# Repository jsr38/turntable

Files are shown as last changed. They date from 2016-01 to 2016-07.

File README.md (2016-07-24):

# turntable
3D scanning turntable

This repository contains hardware designs and firmware to enable a 3D scanning turntable to be constructed.

The turntable operates with either a mains AC motor with feedback or a DC motor.  In both cases a rotary optical encoder is employed to give accurate feedback of current position to upper software layers.

In my fork of the [bqlabs/horus](https://github.com/jsr38/horus) repository you can find my modifications to the bqlabs/horus scanning software which allow either a pair of laser line emitters and RGB camera or a Microsoft Kinect V2 aka Kinect One which contains an IR depth sensor and RGB camera, allowing full colour but lower resolution scans under Linux or Mac OS X.

The turntable electronics are designed to interface to an Arduino Uno as a pair of expansion shields.

opto-interface:
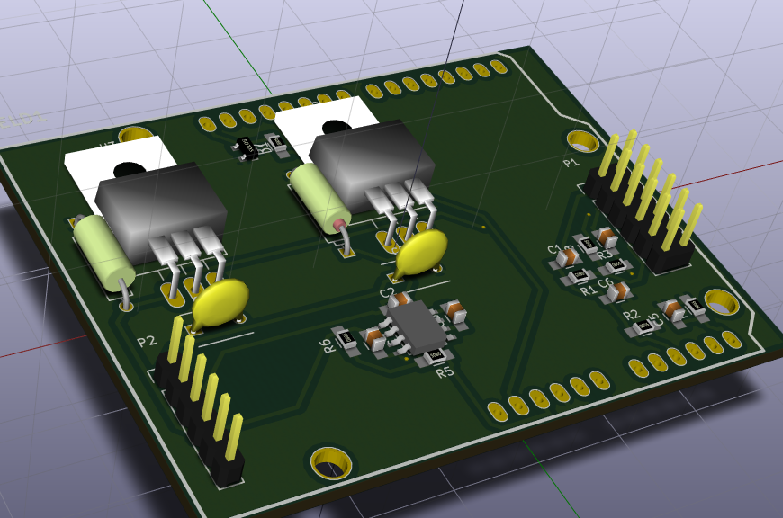
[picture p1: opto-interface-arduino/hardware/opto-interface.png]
Opto Encoder Interface


opto-interface prototype:
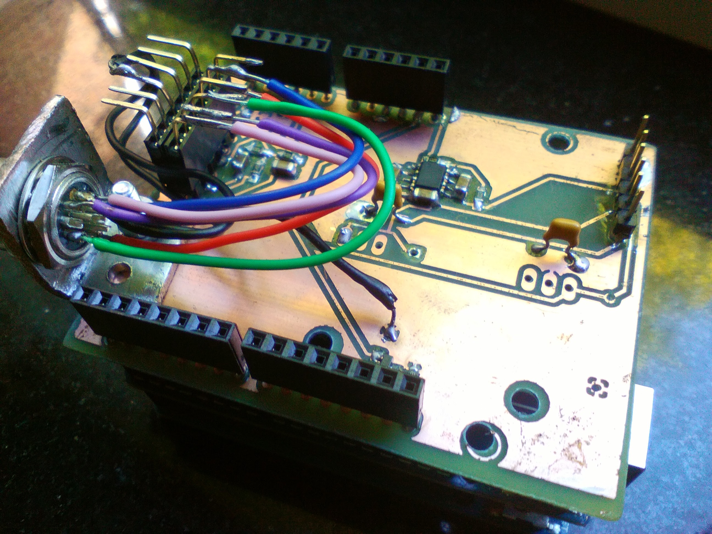
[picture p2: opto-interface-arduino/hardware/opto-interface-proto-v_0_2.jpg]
Opto Encoder Interface Prototype v0.2


* [first movements](https://youtu.be/DPcl0FW12F8)

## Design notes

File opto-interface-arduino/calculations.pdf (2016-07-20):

## 1 MAX889 Charge pump IC

———————
We have MAX889S variant.
PART FREQUENCY C FLY C OUT C IN REGULATED C IN FREE-RUN MAX889S 1MHz 2.2F 10F 10F 2.2F
Output Ripple mV vs Load Current substituting C OUT and a load I=50-100mA , ripple ought to be 5-8mV. Is this OK?
We don’t know because we don’t know exactly what’s inside and there is no indication on the encoder’s datasheet as to tolerance of supply noise/ripple. Ripple should be fundamentally located @fOSC which is 1MHz, so filtering should be straightforward given our estimate for encoder signals of DO SUMS
From the datasheet,

R1 ≤

Vref
30µA

R2 <

−Vout
30µA

Calculate for 12V input and reference at 5V.

R1 ≤

5
30µA = 167kR

R2 <

5
30µA = 167kR

Choose R1 to be less than or equal 100kR.

R1 = 100kR

R2 = R1

Vout

−Vref
=

100e3 − 5
−5

= 100kR

Calculate for 12V input and reference at 12V.

R1 ≤

12
30µA = 400kR

R2 <

5
30µA = 167kR

1

2 Design input filter using spice.

——————————–
Operating fundamental frequency for encoder: 81, 000 ∗ 2 ∗ π rad rev⁻¹ @ 1 rev s⁻¹ maximum, ≥ 81kHz so cutoff ought to be > 100kHz.
Output O/C impedance is 110 ohms @ 100kHz.
Voltage divider to find 600mV between 0V and 5V:

Vout = Vin

Z1
Z1 + Z2

⇒

0.6
5

− 1

Z1 +

0.6
5

Z2 = 0 ⇒ Z1 =

5
0.6

− 1

Z2

If Z2 = 100kR then Z1 = 733kR

### 2.1 Schematic model

### 2.2 Model response

3 Arduino sample rates.

———————
15k SPS or 76.9k SPS at lowest resolution.

2

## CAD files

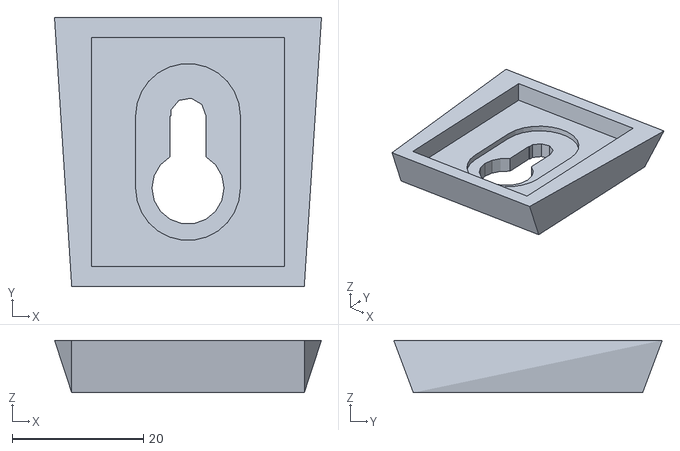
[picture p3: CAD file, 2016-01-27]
tripod/501PL.stl
40.8 x 41.0 x 8.00

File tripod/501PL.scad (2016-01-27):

// A replacement plate for Manfrotto 501PL quick release compatible heads
// by Nirav Patel <http://eclecti.cc>
//
// Altered to suit Velbon Sherpa 250 with PH-157Q
// JSR 2016 

// Available under the CC BY license

channel = 5.5;              // Width of the channel in the middle
height = 8.0;               // Height of the plate (>=11 mm recommended)
length = 19.0 * 2.0 + 3.0; // Length of the plate (90 mm is the stock one)
wall = 3;                   // Thickness of walls
width = 35.5;              // Width of the main cube structure
channel_offset = width / 2.0;

tan_theta = 2.625 / length;

module tapered() polyhedron(points = [[-2.625,0,0], [0,wall,height], [0,0,0], [0,length,0], [0,length - wall,height], [0,length,0]],
        faces = [[0,1,2], [0,4,1], [0,3,4], [0,5,3], [0,2,5], [3,5,4], [2,1,4], [2,4,5]]);
        
module tapered_back() polyhedron(points = [[-2.625 +wall * tan_theta,wall,0], [0,wall,height], [-2.625,0,0], [width + 2.625,0,0], [width,wall,height], [width + 2.625 - wall * tan_theta,wall,0]],
        faces = [[0,1,2], [0,4,1], [0,5,4], [0,3,5], [0,2,3], [3,4,5], [2,1,4], [2,4,3]]);

module tapered_front() polyhedron(points = [[0,length - wall,0], [0,length,0], [0,length - wall,height], [width,length,0], [width,length - wall,height], [width,length - wall,0]],
        faces = [[0,1,2], [0,2,4], [0,4,5], [0,5,1], [1,5,3], [3,5,4], [1,4,2], [1,3,4]]);    

rotate([180,0,0]) // flipped for printability
difference() {
    union() {
        difference() {
            translate([0, wall, 0]) cube([width,length - 2.0 * wall,height]); // the bulk of the box
            translate([wall,wall,0]) cube([width- 2.0 *wall,length - 2 * wall,3.9]);      // removes the base area
            // hollow out what we can to make it use less plastic
            //translate([wall,wall,0]) cube([42/2-2*wall-8,length-2*wall, height-wall]);
            //translate([wall+42/2+8,wall,0]) cube([42/2-2*wall-8,length-2*wall, height-wall]);
        }
        // the tapered side bits
        tapered();
        translate([width,0,0]) mirror([1,0,0]) tapered();
        tapered_back();
        tapered_front();
        // the stop to keep it from falling out the front
        //%translate([0,width,0]) cube([11,4,height]);
        //%translate([0,wall,0]) cube([width - 5.0,wall,height]);
        // the triangle piece that the quickrelease interfaces with
        //polyhedron(points = [[width,width,0], [width,0,0], [width - 5.0,width,0], [width, width, height], [width, 0, height], [width - 5.0, width, height]],
        //    faces = [[0,2,1],[0,1,3],[1,4,3],[2,4,1],[2,5,4],[0,3,5],[0,5,2],[5,3,4]]);
    }

    // the channel for the camera mount screw
    translate([channel_offset,15,0]) cylinder(h=height,r=channel/2);
    translate([channel_offset-channel/2,15,0]) cube([channel,length-30,height]);
    translate([channel_offset-8,15,0]) cube([16,length-30,5]);
    translate([channel_offset,15,0]) cylinder(h=5,r=8);
    translate([channel_offset,length-15,0]) cylinder(h=5,r=8);
    translate([channel_offset,length-15,0]) cylinder(h=height, r=channel);
}

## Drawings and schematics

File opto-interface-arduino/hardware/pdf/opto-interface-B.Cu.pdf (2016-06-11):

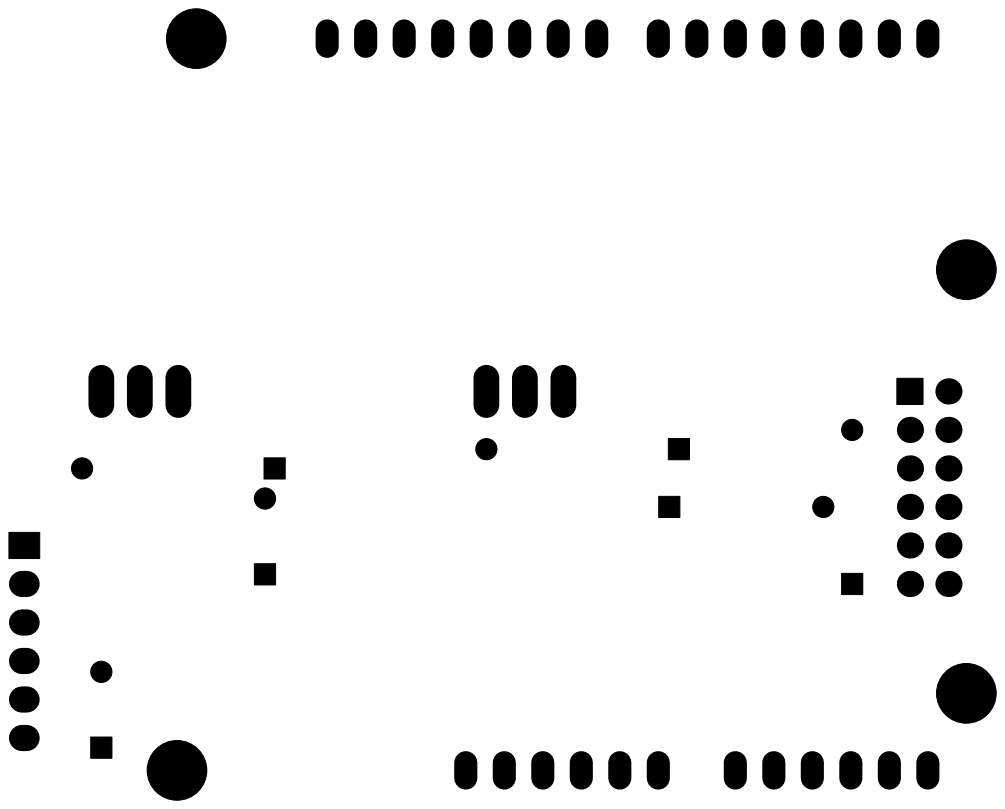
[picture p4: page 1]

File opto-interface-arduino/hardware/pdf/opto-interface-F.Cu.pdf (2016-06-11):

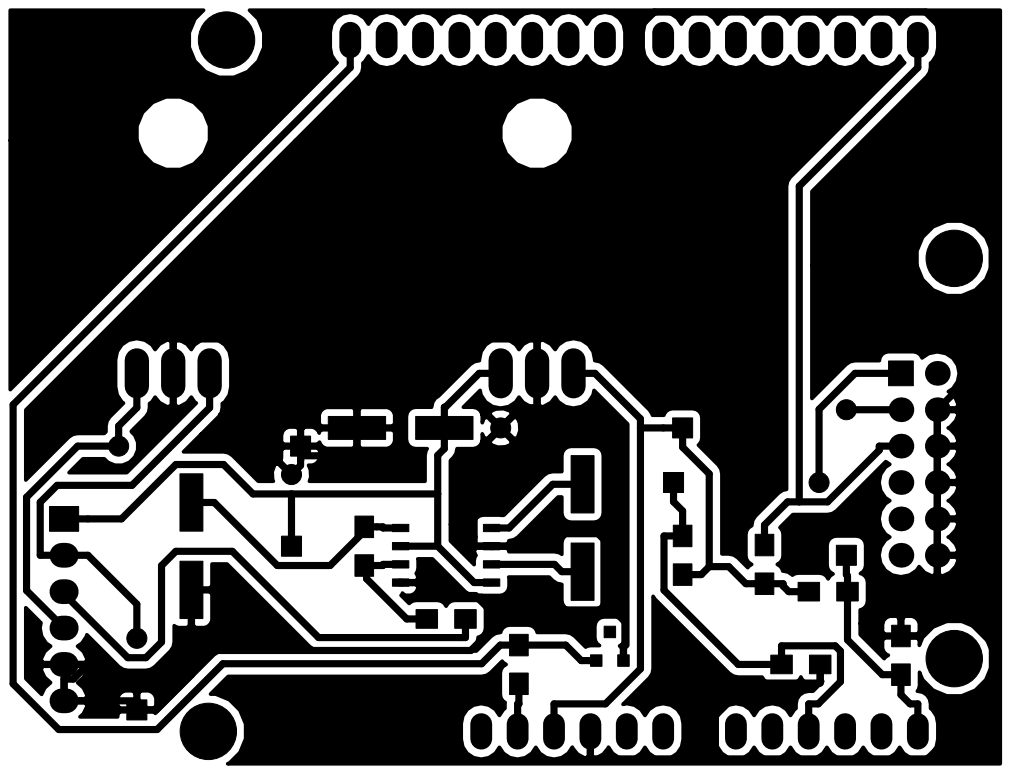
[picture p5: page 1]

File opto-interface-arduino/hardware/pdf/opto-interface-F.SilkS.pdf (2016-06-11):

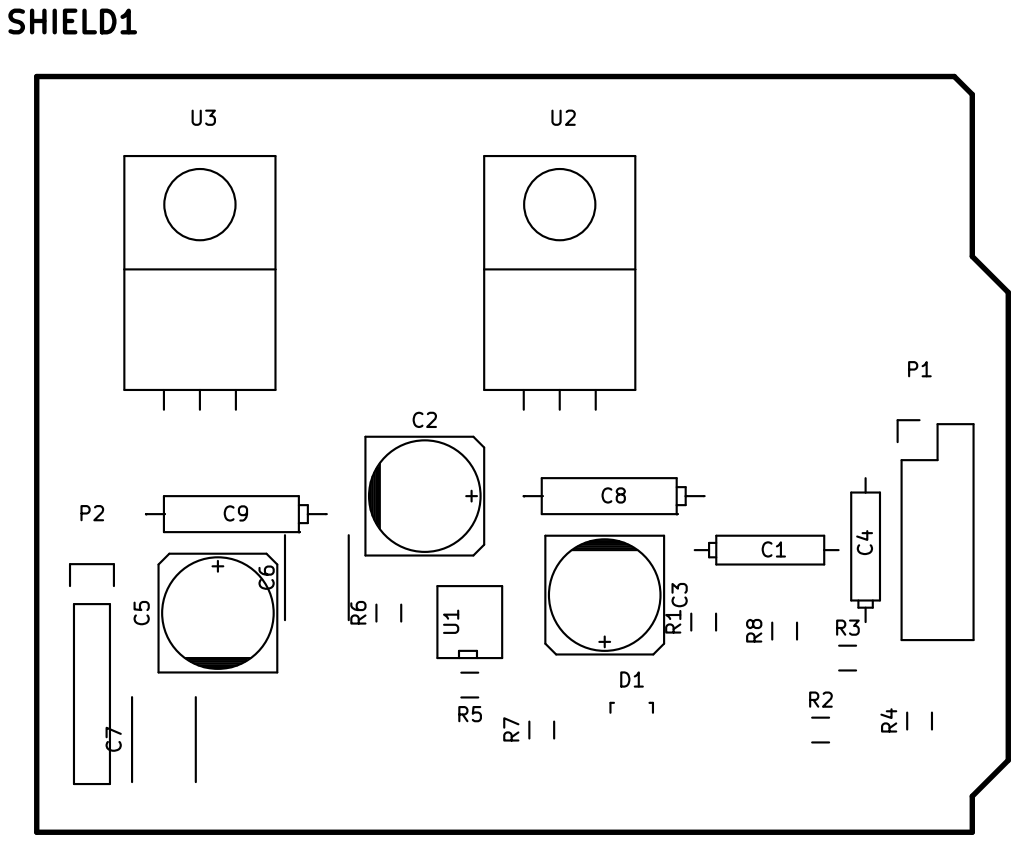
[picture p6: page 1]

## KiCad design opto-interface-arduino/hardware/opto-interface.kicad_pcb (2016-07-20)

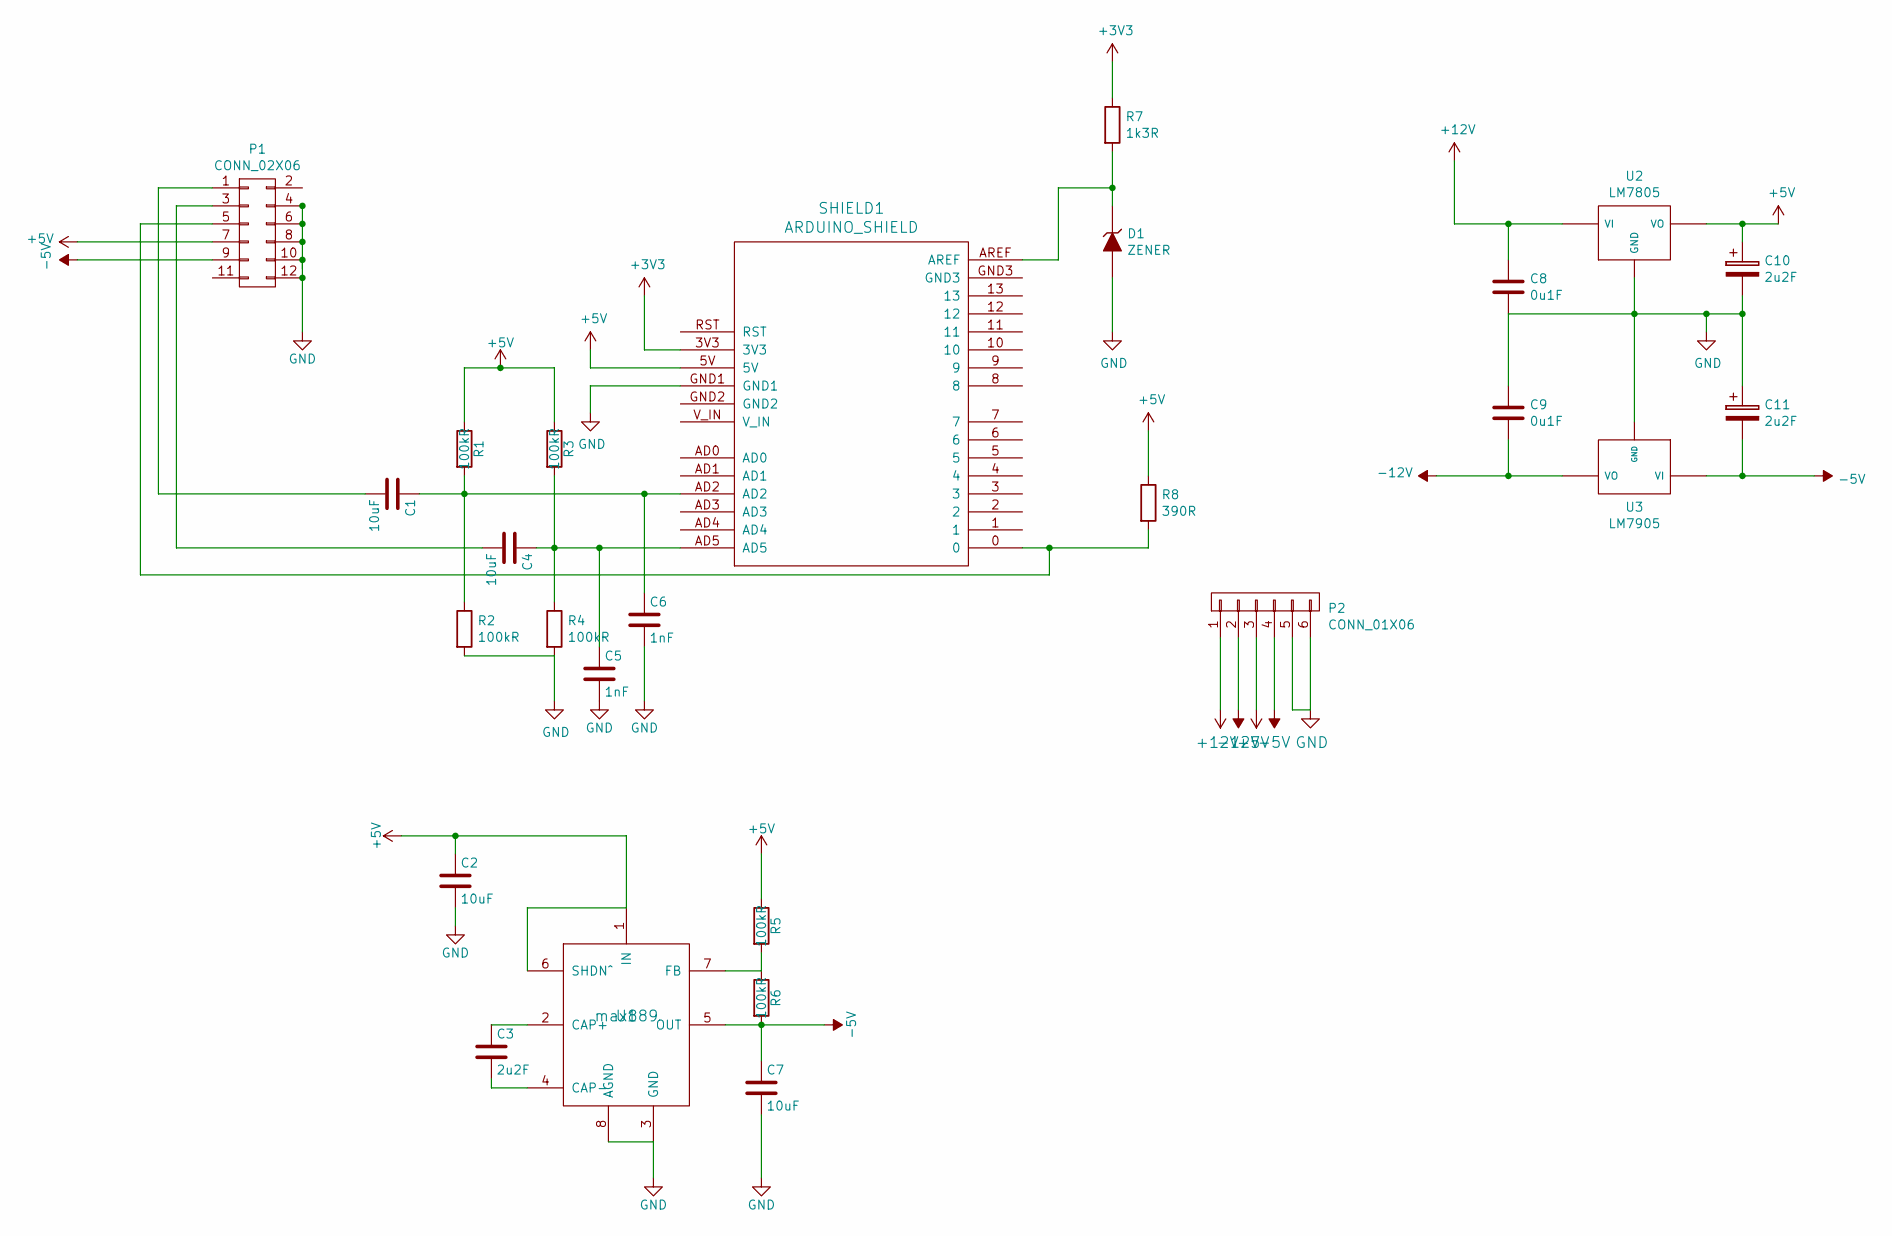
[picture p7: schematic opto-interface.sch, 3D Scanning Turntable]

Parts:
C1, C2, C4, C7: 10uF; C_0805_HandSoldering
C3: 2u2F; C_0805_HandSoldering
C5, C6: 1nF; C_0805_HandSoldering
C8, C9: 0u1F; C_Disc_D6_P5
C10, C11: 2u2F; CP5
D1: ZENER; SOT-23
P1: CONN_02X06; Pin_Header_Straight_2x06
P2: CONN_01X06; Pin_Header_Straight_1x06
R1, R2, R3, R4, R5, R6: 100kR; R_0805_HandSoldering
R7: 1k3R; R_0805_HandSoldering
R8: 390R; R_0805_HandSoldering
SHIELD1: ARDUINO_SHIELD; ARDUINO SHIELD
U1: max889; SOIC-8-N
U2: LM7805; TO-220_regul_Horizontal_LargePads
U3: LM7905; TO-220_regul_Horizontal_LargePads

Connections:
+3V3: R7.1, SHIELD1.3V3
+5V: C2.1, C10.1, P1.7, P2.3, R1.1, R3.1, R5.1, R8.1, SHIELD1.5V, U1.1 (IN), U1.6 (SHDN^), U2.VO
+12V: C8.1, P2.1, U2.VI
-5V: C7.1, C11.2, P1.9, P2.4, R6.2, U1.5 (OUT), U3.VI
-12V: C9.2, P2.2, U3.VO
GND: C2.2, C5.2, C6.2, C7.2, C8.2, C9.1, C10.2, C11.1, D1.2 (A), P1.4, P1.6, P1.8, P1.10, P1.12, P2.5, P2.6, R2.2, R4.2, SHIELD1.GND1, U1.3 (GND), U1.8 (AGND), U2.GND, U3.GND
unnamed: C1.1, C6.1, R1.2, R2.1, SHIELD1.AD2
unnamed: C1.2, P1.1
unnamed: C3.1, U1.2 (CAP+)
unnamed: C3.2, U1.4 (CAP-)
unnamed: C4.1, C5.1, R3.2, R4.1, SHIELD1.AD5
unnamed: C4.2, P1.3
unnamed: D1.1 (K), R7.2, SHIELD1.AREF
unnamed: P1.5, R8.2, SHIELD1.0
unnamed: R5.2, R6.1, U1.7 (FB)

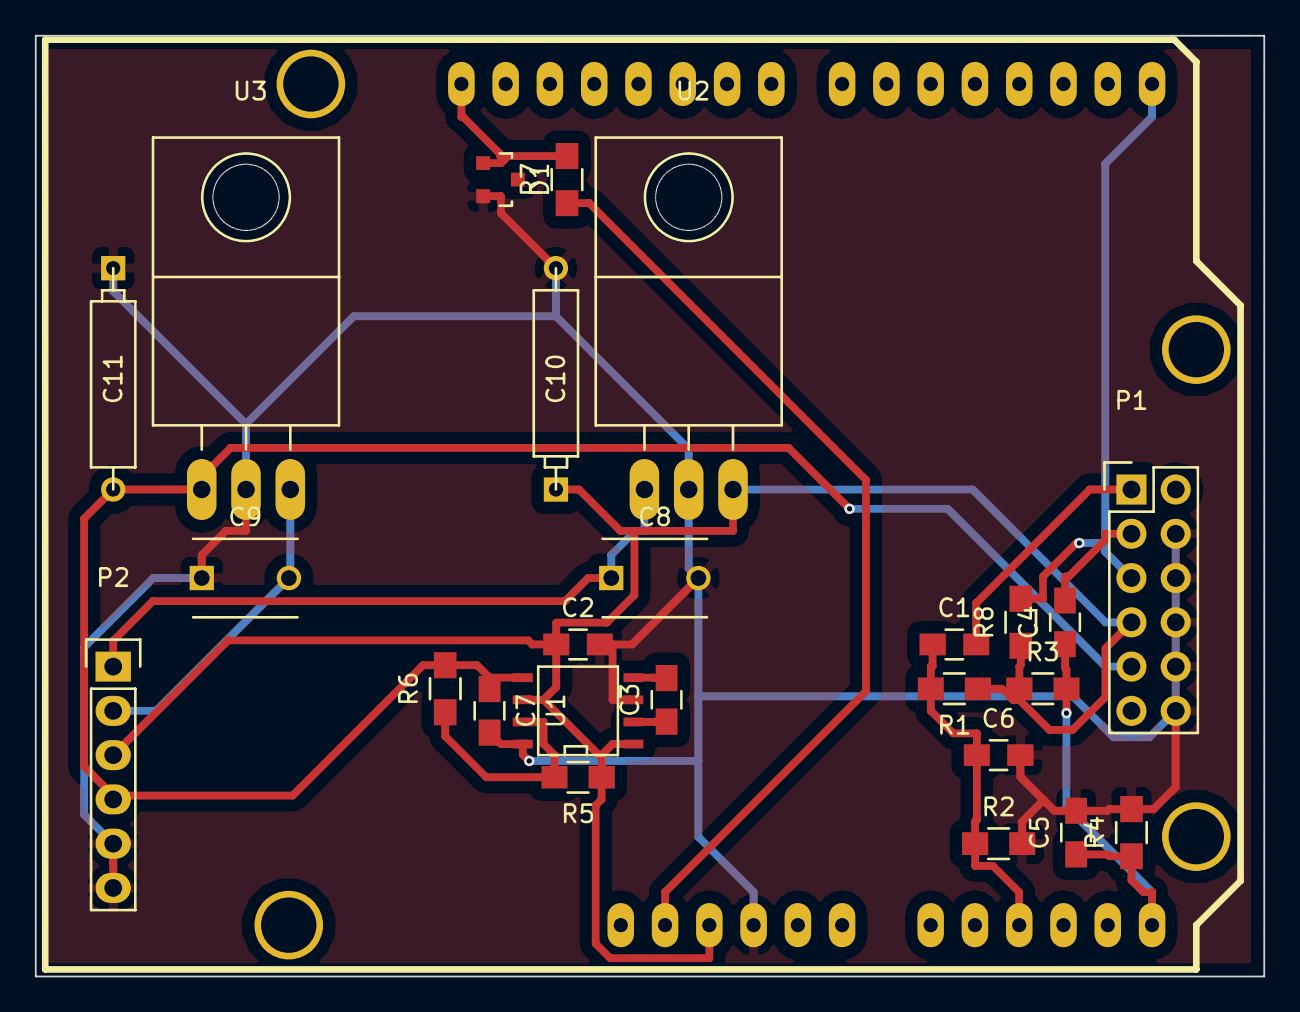
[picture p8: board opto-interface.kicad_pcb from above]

Board: 2 copper layers, 70.5 x 54.0 mm, 26 parts (0 on the bottom side), 15 nets.

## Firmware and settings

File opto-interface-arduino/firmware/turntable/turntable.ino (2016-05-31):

/*                                                                      
 *
 * @(#)turntable.ino
 *
 * Copyright (c) 2016 Argusat Limited
 * 10 Underwood Road,  Southampton.  UK
 * All rights reserved.
 *
 * This software is the confidential and proprietary information of
 * Argusat Limited. ("Confidential Information").  You shall not
 * disclose such Confidential Information and shall use it only in
 * accordance with the terms of the license agreement you entered into
 * with Argusat Limited.
 *
 
  ReadAnalogVoltage
  Reads an analog input on pin 0, converts it to voltage, and prints the result to the serial monitor.
  Graphical representation is available using serial plotter (Tools > Serial Plotter menu)
  Attach the center pin of a potentiometer to pin A0, and the outside pins to +5V and ground.

  This example code is in the public domain.
*/

#include <Servo.h>
#include "Turntable.h"
#include "serial.h"
#include "gcode.h"
#include "protocol.h"


// the setup routine runs once when you press reset:
void setup() {
  // initialize serial communication 
  serial_init();
  serial_reset_read_buffer(); // Clear serial read buffer
  gc_init();
}

// the loop routine runs over and over again forever:
void loop() {
  protocol_main_loop();
}

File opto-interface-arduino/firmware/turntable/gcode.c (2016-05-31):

/*
  gcode.c - rs274/ngc parser.
  Part of Grbl

  Copyright (c) 2011-2015 Sungeun K. Jeon
  Copyright (c) 2009-2011 Simen Svale Skogsrud

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
  You should have received a copy of the GNU General Public License
  along with Grbl.  If not, see <http://www.gnu.org/licenses/>.
*/

//#include "grbl.h"

// NOTE: Max line number is defined by the g-code standard to be 99999. It seems to be an
// arbitrary value, and some GUIs may require more. So we increased it based on a max safe
// value when converting a float (7.2 digit precision)s to an integer.
#define MAX_LINE_NUMBER 9999999 

#define AXIS_COMMAND_NONE 0
#define AXIS_COMMAND_NON_MODAL 1 
#define AXIS_COMMAND_MOTION_MODE 2
#define AXIS_COMMAND_TOOL_LENGTH_OFFSET 3 // *Undefined but required

// Declare gc extern struct
parser_state_t gc_state;
parser_block_t gc_block;

#define FAIL(status) return(status);


void gc_init() 
{
  memset(&gc_state, 0, sizeof(parser_state_t));
  
  // Load default G54 coordinate system.
  if (!(settings_read_coord_data(gc_state.modal.coord_select,gc_state.coord_system))) { 
    report_status_message(STATUS_SETTING_READ_FAIL); 
  } 
}


// Sets g-code parser position in mm. Input in steps. Called by the system abort and hard
// limit pull-off routines.
void gc_sync_position() 
{
  system_convert_array_steps_to_mpos(gc_state.position,sys.position);
}


static uint8_t gc_check_same_position(float *pos_a, float *pos_b) 
{
  uint8_t idx;
  for (idx=0; idx<N_AXIS; idx++) {
    if (pos_a[idx] != pos_b[idx]) { return(false); }
  }
  return(true);
}
         
// Executes one line of 0-terminated G-Code. The line is assumed to contain only uppercase
// characters and signed floating point values (no whitespace). Comments and block delete
// characters have been removed. In this function, all units and positions are converted and 
// exported to grbl's internal functions in terms of (mm, mm/min) and absolute machine 
// coordinates, respectively.
uint8_t gc_execute_line(char *line) 
{
  /* -------------------------------------------------------------------------------------
     STEP 1: Initialize parser block struct and copy current g-code state modes. The parser
     updates these modes and commands as the block line is parser and will only be used and
     executed after successful error-checking. The parser block struct also contains a block
     values struct, word tracking variables, and a non-modal commands tracker for the new 
     block. This struct contains all of the necessary information to execute the block. */

  memset(&gc_block, 0, sizeof(parser_block_t)); // Initialize the parser block struct.
  memcpy(&gc_block.modal,&gc_state.modal,sizeof(gc_modal_t)); // Copy current modes
  uint8_t axis_command = AXIS_COMMAND_NONE;
  uint8_t axis_0, axis_1, axis_linear;
  uint8_t coord_select = 0; // Tracks G10 P coordinate selection for execution
  float coordinate_data[N_AXIS]; // Multi-use variable to store coordinate data for execution
  float parameter_data[N_AXIS]; // Multi-use variable to store parameter data for execution
  
  // Initialize bitflag tracking variables for axis indices compatible operations.
  uint8_t axis_words = 0; // XYZ tracking
  uint8_t ijk_words = 0; // IJK tracking 

  // Initialize command and value words variables. Tracks words contained in this block.
  uint16_t command_words = 0; // G and M command words. Also used for modal group violations.
  uint16_t value_words = 0; // Value words. 

  /* -------------------------------------------------------------------------------------
     STEP 2: Import all g-code words in the block line. A g-code word is a letter followed by
     a number, which can either be a 'G'/'M' command or sets/assigns a command value. Also, 
     perform initial error-checks for command word modal group violations, for any repeated
     words, and for negative values set for the value words F, N, P, T, and S. */
     
  uint8_t word_bit; // Bit-value for assigning tracking variables
  uint8_t char_counter = 0;  
  char letter;
  float value;
  uint8_t int_value = 0;
  uint16_t mantissa = 0;

  while (line[char_counter] != 0) { // Loop until no more g-code words in line.
    
    // Import the next g-code word, expecting a letter followed by a value. Otherwise, error out.
    letter = line[char_counter];
    if((letter < 'A') || (letter > 'Z')) { FAIL(STATUS_EXPECTED_COMMAND_LETTER); } // [Expected word letter]
    char_counter++;
    if (!read_float(line, &char_counter, &value)) { FAIL(STATUS_BAD_NUMBER_FORMAT); } // [Expected word value]

    // Convert values to smaller uint8 significand and mantissa values for parsing this word.
    // NOTE: Mantissa is multiplied by 100 to catch non-integer command values. This is more 
    // accurate than the NIST gcode requirement of x10 when used for commands, but not quite
    // accurate enough for value words that require integers to within 0.0001. This should be
    // a good enough comprimise and catch most all non-integer errors. To make it compliant, 
    // we would simply need to change the mantissa to int16, but this add compiled flash space.
    // Maybe update this later. 
    int_value = trunc(value);
    mantissa =  round(100*(value - int_value)); // Compute mantissa for Gxx.x commands.
        // NOTE: Rounding must be used to catch small floating point errors.
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

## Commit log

2016-01-16 Datasheet and web pages for Canon K-1 optical rotary encoder
2016-01-18 Initial commit of tripod QR plate
    [501PL.scad]
2016-01-18 Modify to suit Velbon Sherpa 250 tripod with PH-157Q head.
    [501PL.scad]
2016-01-18 Add QR plate STL file
    [501PL.stl]
2016-01-18 Intial commit of PCB and Arduion sketch for controller.
    [opto-interface.kicad_pcb, opto-interface.sch]
2016-01-20 Remove spurious scad file...
    [501PL.scad]
2016-01-20 Try again :\(
    [501PL.scad]
2016-01-25 Tidy up, rename .ino to something valid ;) Update to latest QR mount plate design.
    [501PL.scad, 501PL.stl, opto-interface.kicad_pcb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]
2016-01-25 Make Arduino happy :(
2016-01-25 Add Arduino shield component and PCB files. Begin schematic capture.
    [opto-interface.sch]
2016-01-27 Move current Kicad files to hardware subdirectory. Update tripod QR plate to be slightly less wide.
    [501PL.scad, 501PL.stl, opto-interface.kicad_pcb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]
2016-01-27 Add library papers and do initial Arduino Shield board layout.
    [opto-interface.sch]
2016-01-31 Move encoder primer to github
2016-02-06 Update to include external power connector.
    [opto-interface.kicad_pcb, opto-interface.sch]
2016-02-11 Add charge pump data sheet MAX889
2016-03-03 Relocate opto-encoder documentation to library/
2016-03-04 Add charge pump for -ve supply and skeleton input filter. Add calculations document.
    [opto-interface.sch]
2016-03-04 Add spice schematic for ADC front-end sim.
    [analogue_filter_adc_frontend.sch]
2016-03-07 Start firmware. Add serial and gocde parser from Grbl. Update simulations of LP filter and level shifter for ADC frontend.
    [analogue_filter_adc_frontend.sch]
2016-03-13 AC sweep 10Hz - 120kHz (Bode plot)
    [analogue_filter_adc_frontend.sch]
2016-05-31 Add filter simulations, first pass layout, some calculations and some skeleton code.
    [analogue_filter_adc_frontend.sch, opto-interface.dsn, opto-interface.kicad_pcb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]
2016-06-11 Complete v 0.1 layout
    [opto-interface.dsn, opto-interface.kicad_pcb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]
2016-07-05 Add borniers kicad library. Add polarization based 3d scan paper, references and book chapter on optical-material interactions.
2016-07-20 Modify layout to ahem follow the datasheet guidance on MAX889. Update analogue input schematic for simulation to accomodate steeper low-pass roll-off.
    [analogue_filter_adc_frontend.sch, opto-interface.dsn, opto-interface.kicad_pcb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]
2016-07-24 Add photo of prototype opto interface to README.md

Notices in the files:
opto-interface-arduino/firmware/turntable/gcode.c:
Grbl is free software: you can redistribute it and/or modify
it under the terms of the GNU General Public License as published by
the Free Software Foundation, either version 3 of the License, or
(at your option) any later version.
